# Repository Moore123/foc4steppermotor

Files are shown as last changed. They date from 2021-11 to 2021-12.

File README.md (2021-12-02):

### foc4steppermotor

The target of this project is to create a board for developing protocol of FOC steppermotor controler

### Passed:
```
    1.extern board power feed
    2.MCU running
    3.MCU flash
```

### Tobe test:
```
    1.FOC driven steppermotor
    2.rs485 
    3.A13333 SPI feed back
```

### MayBe FIX
```
    SWIO  <- pull-up
    SWCLK <- pull-dn
```

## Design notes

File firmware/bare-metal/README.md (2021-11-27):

# pill\_blink, bare metal version for basic TEST

To build this project:

1. Ensure you have the ARM GCC compiler installed (e.g. install [Homebrew](https://brew.sh), run `brew cask install gcc-arm-embedded`)
2. `make all`
3. The binary should now be available for flashing in `pill_blink.bin`

Written as bare metal no library dependencies

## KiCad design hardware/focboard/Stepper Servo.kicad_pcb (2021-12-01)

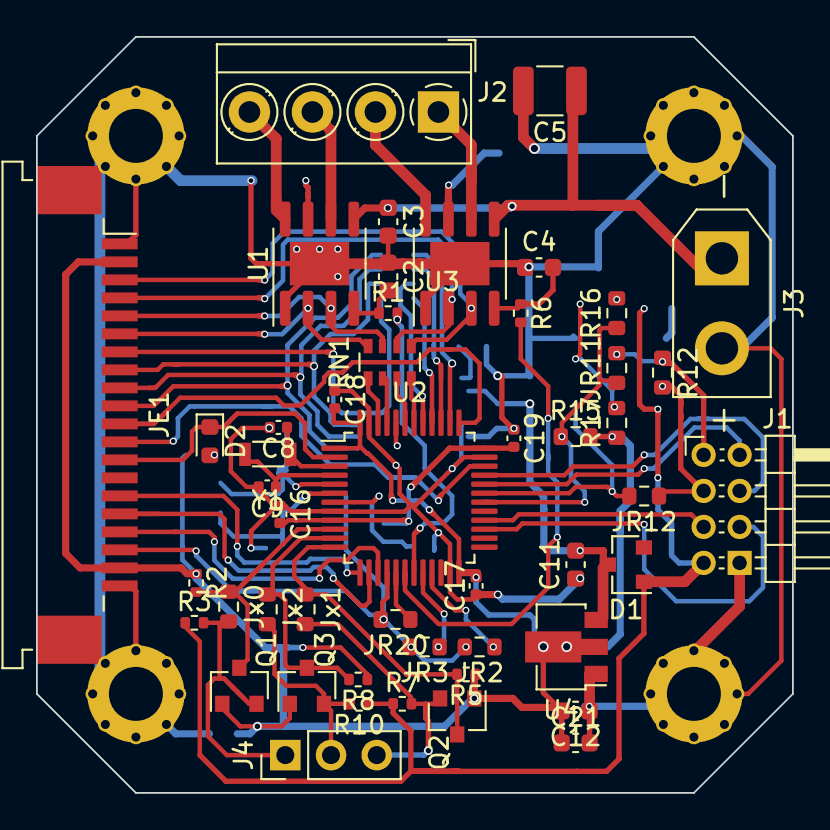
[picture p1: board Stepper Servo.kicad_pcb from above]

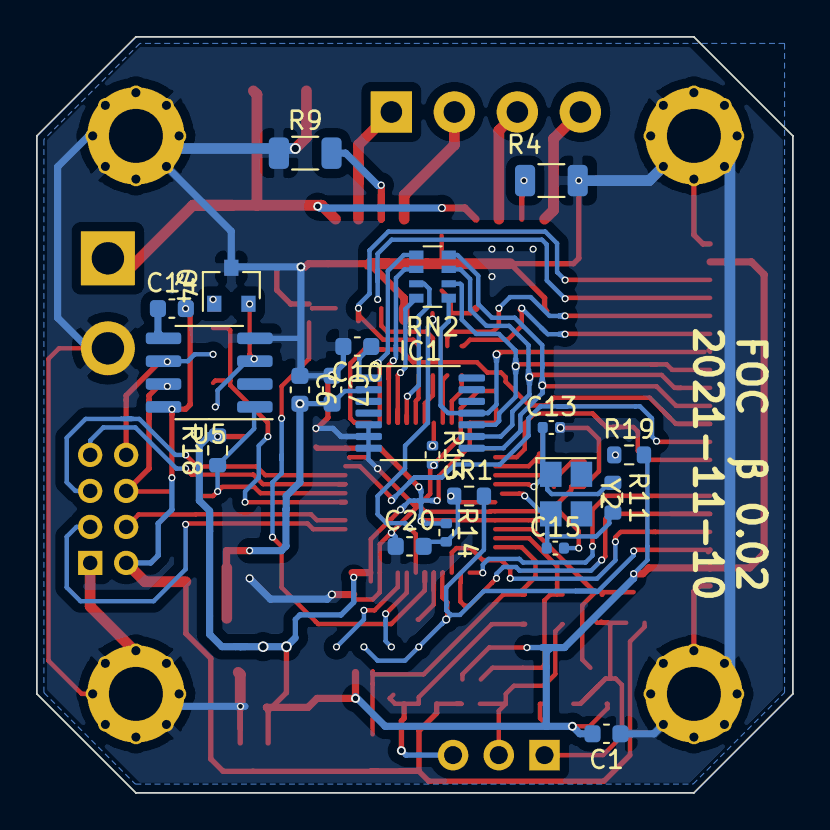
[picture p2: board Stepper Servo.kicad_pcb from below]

Board: 2 copper layers, 42.0 x 42.0 mm, 74 parts (21 on the bottom side), 66 nets.

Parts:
C1, C2, C3, C4, C6, C7, C10, C20, C21: 100nF; C_0603_1608Metric
C5: 100uF; C_1210_3225Metric
C8, C9: 10pF; C_0402_1005Metric
C11: 10uF; C_0603_1608Metric
C12: 22uf; C_0603_1608Metric
C13, C15: 22pF; C_0402_1005Metric
C14: 0.1uF; C_0603_1608Metric
C16, C17, C18, C19: 100nF; C_0402_1005Metric
D1: BAT64-05; SOT-23
D2: LED; LED_0603_1608Metric
H1, H2, H3, H4: MountingHole_Pad; MountingHole_3.2mm_M3_Pad_Via
IC1: A1333LLETR-5-T; TSSOP-14_4.4x5mm_P0.65mm
J1: Inputs; PinHeader_2x04_P2.00mm_Horizontal
J2: Motor; TerminalBlock_MetzConnect_Type059_RT06304HBWC_1x04_P3.50mm_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
J3: Conn_01x02_MountingPin; AMASS_XT30UPB-F_1x02_P5.0mm_Vertical
J4: Conn_01x03_Female; PinHeader_1x03_P2.54mm_Vertical
JE1: Conn_01x20; TE_2-84953-0_1x20-1MP_P1.0mm_Horizontal
JR1, JR2, JR3, JR20: 0R; R_0603_1608Metric
JR11, JR12: 0; R_0603_1608Metric
Jx0, Jx1, Jx2: 0; R_0603_1608Metric
Q1, Q2, Q3: FDN337N; SOT-23
Q4: Q_NPN_BCE; SOT-23
R1, R6: 1K; R_0402_1005Metric
R2, R3, R5, R7, R8, R10, R13, R14: 10K; R_0402_1005Metric
R4, R9: 0.1; R_1206_3216Metric
R11: 1M; R_0603_1608Metric
R12: 120R; R_0603_1608Metric
R15, R17, R18: 10K; R_0603_1608Metric
R16: 1K; R_0603_1608Metric
R19: 1k; R_0603_1608Metric
RN1: 100; R_Array_Convex_4x0603
RN2: 10; R_Array_Convex_4x0603
U1, U3: A4950E; SOIC-8-1EP_3.9x4.9mm_P1.27mm_EP2.41x3.3mm
U2: STM32F030CCTx; LQFP-48_7x7mm_P0.5mm
U4: AMS1117-3.3; SOT-89-3
U5: MAX485E; SOP-8_3.76x4.96mm_P1.27mm
Y1: 32K768; FC-135_32768kHz Crystal
Y2: 8MHz; Crystal_SMD_3225-4Pin_3.2x2.5mm

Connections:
1A: J2.2, U3.8
1B: J2.1, U3.6
2A: J2.4, U1.8
2B: J2.3, U1.6
+3V3: C1.2, C12.2, C16.2, C17.2, C18.2, C19.2, C21.1, JE1.2, JE1.19, Q1.1, Q2.1, Q3.1, R2.1, R5.1, R8.1, R14.1, R15.2, R17.1, R18.2, R19.2, U2.1, U2.9, U2.24, U2.36, U2.48, U4.2
+5V: C6.2, C7.2, C11.2, D1.3, IC1.2, U4.3
A2: RN2.5, U2.38
A2_1: IC1.8, JE1.10, RN2.4
A9450_IN1: RN1.4, U2.42
A9450_IN2: RN1.3, U2.43
A9450_IN3: RN1.2, U2.45
A9450_IN4: RN1.1, U2.46
BOOT0: R13.1, U2.44
BackEnable: J1.4, U2.33
DIR: J4.2, Jx2.2, Q3.2, R10.2
DIR1: Jx2.1, Q3.3, R8.2, U2.11
E13: JE1.15, U2.13
E14: JE1.16, U2.14
E15: JE1.17, U2.15
EJ16: JE1.18, JR1.2, JR2.2, JR3.2, JR20.2, U2.16
EJ17: JR20.1, U2.17
EJ20: JR3.1, U2.20
EJ21: JR2.1, U2.21
EN: J4.3, Jx1.2, Q2.2, R7.2
EN1: Jx1.1, Q2.3, R5.2, U2.12
FrontEnable: J1.2, U2.32
GND: C1.1, C2.1, C3.2, C4.1, C5.2, C6.1, C7.1, C8.2, C9.2, C10.2, C11.1, C12.1, C13.2, C15.2, C16.1, C17.1, C18.1, C19.1, C20.1, C21.2, H1.1, H2.1, H3.1, H4.1, IC1.5, IC1.6, IC1.7, J1.8, J3.2, JE1.1, JE1.20, Q4.3, R4.1, R9.1, R13.2, U1.1, U1.9, U2.8, U2.23, U2.35, U2.47, U3.1, U3.9, U4.1, U5.4
IN1: JE1.3, RN1.5, U3.3
IN2: JE1.4, RN1.6, U3.2
IN3: JE1.5, RN1.7, U1.3
IN4: JE1.6, RN1.8, U1.2
LeftEnable: J1.5, U2.28
MAX485A: J1.1, JR11.2, R12.1, U5.6
MAX485B: J1.3, JR12.1, R12.2, U5.7
MISO: RN2.8, U2.40
MISO1: IC1.11, JE1.7, RN2.1
MOSI: RN2.7, U2.41
MOSI1: IC1.10, JE1.8, RN2.2
NRST: C20.2, JR1.1, R14.2, U2.7
unnamed: C2.2, R1.1, U1.4
unnamed: C4.2, R6.1, U3.4
unnamed: C10.1, IC1.1
unnamed: C14.1, U5.5
unnamed: D2.2, R19.1
unnamed: Q4.1, R16.2
unnamed: Q4.2, R17.2, U5.3
unnamed: R4.2, U1.7
unnamed: R9.2, U3.7
OSC32IN: C8.1, U2.3, Y1.1
OSC32OUT: C9.1, U2.4, Y1.2
RightEnable: J1.6, U2.27
SCK: RN2.6, U2.39
SCK1: IC1.9, JE1.9, RN2.3
STP: J4.1, Jx0.2, Q1.2, R3.2
STP1: Jx0.1, Q1.3, R2.2, U2.10
SWCLK: JE1.11, U2.37
SWDIO: JE1.12, U2.34
USART1_RX: JR12.2, R18.1, U2.31, U5.1
USART1_TX: JR11.1, R15.1, R16.1, U2.30
VCC: C14.2, D1.1, J1.7, R3.1, R7.1, R10.1, U5.8
VMOT: C3.1, C5.1, J3.1, U1.5, U3.5
VREF12: R6.2, U2.18
VREF34: R1.2, U2.19
XTALin: C13.1, R11.1, U2.5, Y2.1
XTALout: C15.1, R11.2, U2.6, Y2.2
bLED: D2.1, JE1.13, U2.2

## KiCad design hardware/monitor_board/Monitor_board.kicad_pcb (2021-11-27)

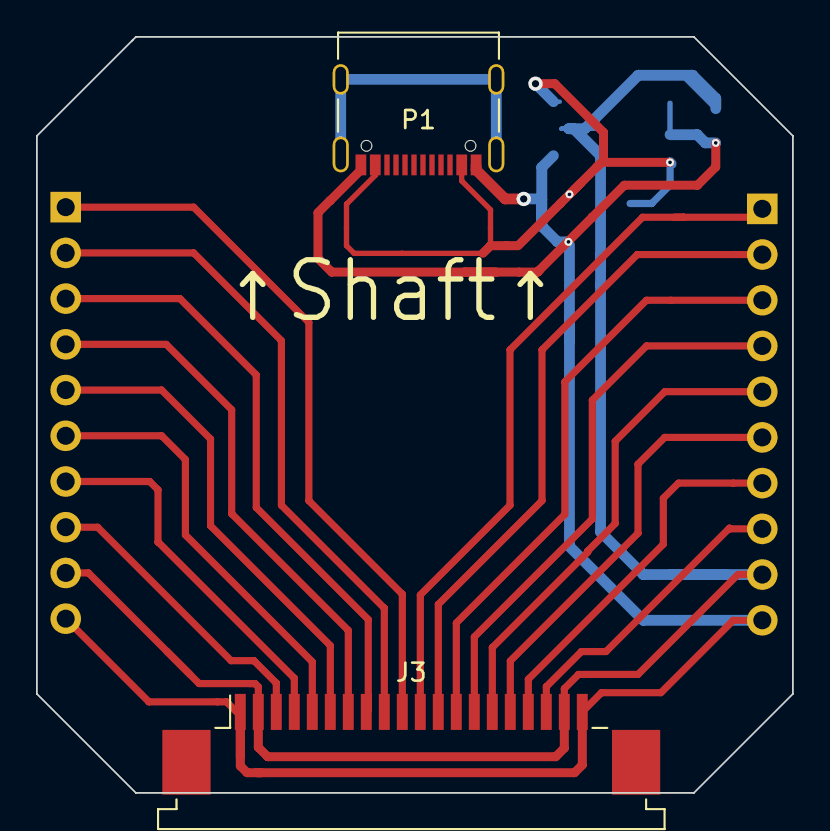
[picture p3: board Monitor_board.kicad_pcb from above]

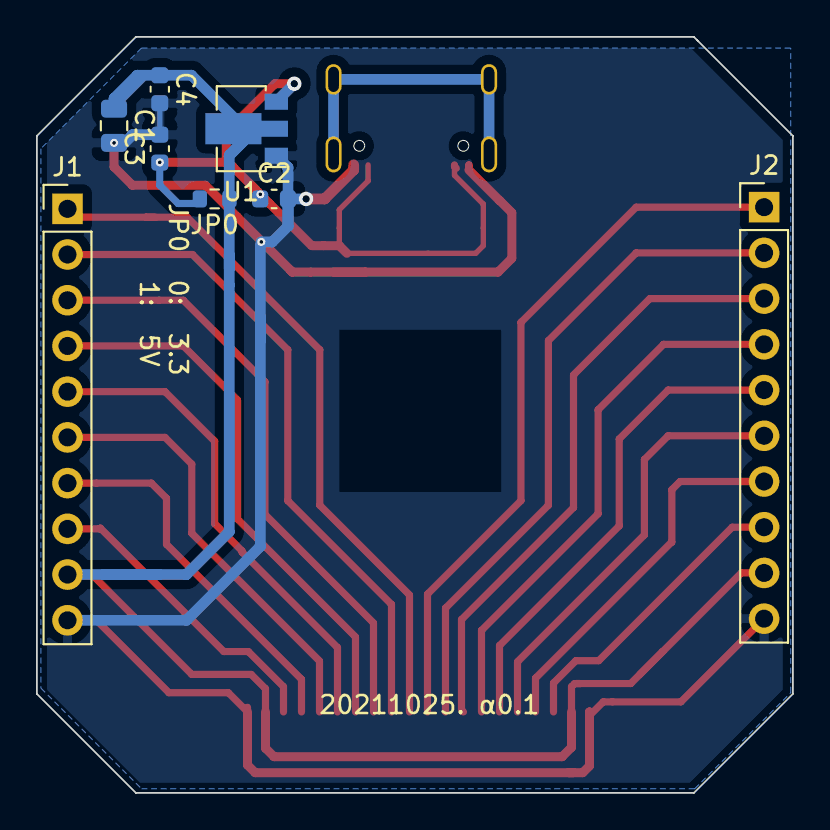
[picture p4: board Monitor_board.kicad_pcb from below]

Board: 2 copper layers, 42.0 x 42.0 mm, 10 parts (8 on the bottom side), 19 nets.

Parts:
C1: 22uF; C_0805_2012Metric
C2: C; C_0603_1608Metric
C3, C4: 0.1uF; C_0603_1608Metric
J1, J2: Conn_01x10_Female; PinHeader_1x10_P2.54mm_Vertical
J3: Conn_01x20_MountingPin; TE_2-84953-0_1x20-1MP_P1.0mm_Horizontal
JP0: 0; R_0603_1608Metric
P1: USB_C_Plug; USB_C_Receptacle_Palconn_UTC16-G
U1: AP1117-33; SOT-89-3

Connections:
GND: C1.2, C2.2, C3.2, C4.2, J1.10, J2.10, J3.1, J3.20, P1.A1, P1.A12, P1.B1, P1.B12, U1.1
unnamed: C1.1, C4.1, J1.9, J2.9, J3.2, J3.19, JP0.1, U1.2
unnamed: C2.1, C3.1, JP0.2, P1.A4, P1.A9, P1.B4, P1.B9, U1.3
unnamed: J1.1, J3.11
unnamed: J1.2, J3.12
unnamed: J1.3, J3.13
unnamed: J1.4, J3.14
unnamed: J1.5, J3.15
unnamed: J1.6, J3.16
unnamed: J1.7, J3.17
unnamed: J1.8, J3.18
unnamed: J2.1, J3.10
unnamed: J2.2, J3.9
unnamed: J2.3, J3.8
unnamed: J2.4, J3.7
unnamed: J2.5, J3.6
unnamed: J2.6, J3.5
unnamed: J2.7, J3.4
unnamed: J2.8, J3.3

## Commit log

2021-11-27 add bare-metal firmware for enssential testing board
2021-11-27 append extern board schema
    [Monitor_board.kicad_pcb, Monitor_board.sch]
2021-12-01 typo & foc4 board
    [Stepper Servo.kicad_pcb, Stepper Servo.sch]
